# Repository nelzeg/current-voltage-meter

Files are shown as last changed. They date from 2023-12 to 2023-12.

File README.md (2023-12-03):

# Current and Voltage Meter

Battery-powered electronic circuit that wirelessly measures and transmits the voltages and currents generated by two solar panels used to power an LED-illuminated plant growth system.

> Download the full [report](./Current_Voltage_Meter_Spanish.pdf)

## Content
- [Operation Mode](README.md#operation-mode)
- [Schematic](README.md#schematic)
- [PCB](README.md#pcb)

### Operation Mode
- Detection system that can measure voltages up to 25 [V] and currents up to 5 [A].
- Operating time range 9:00 AM - 4:00 PM.
- The system senses current 3 times during the first 15 minutes of each hour, the remaining 45 minutes it enters deep sleep mode..

### Schematic
Main components:
- **`INA219AIDR` current sensor** from *Texas Instruments*
- **`ESP32-WROOM-32E` microcontroller** from *Expressif*
- **`TPS62840` DC-DC converter** from *Texas Instruments*

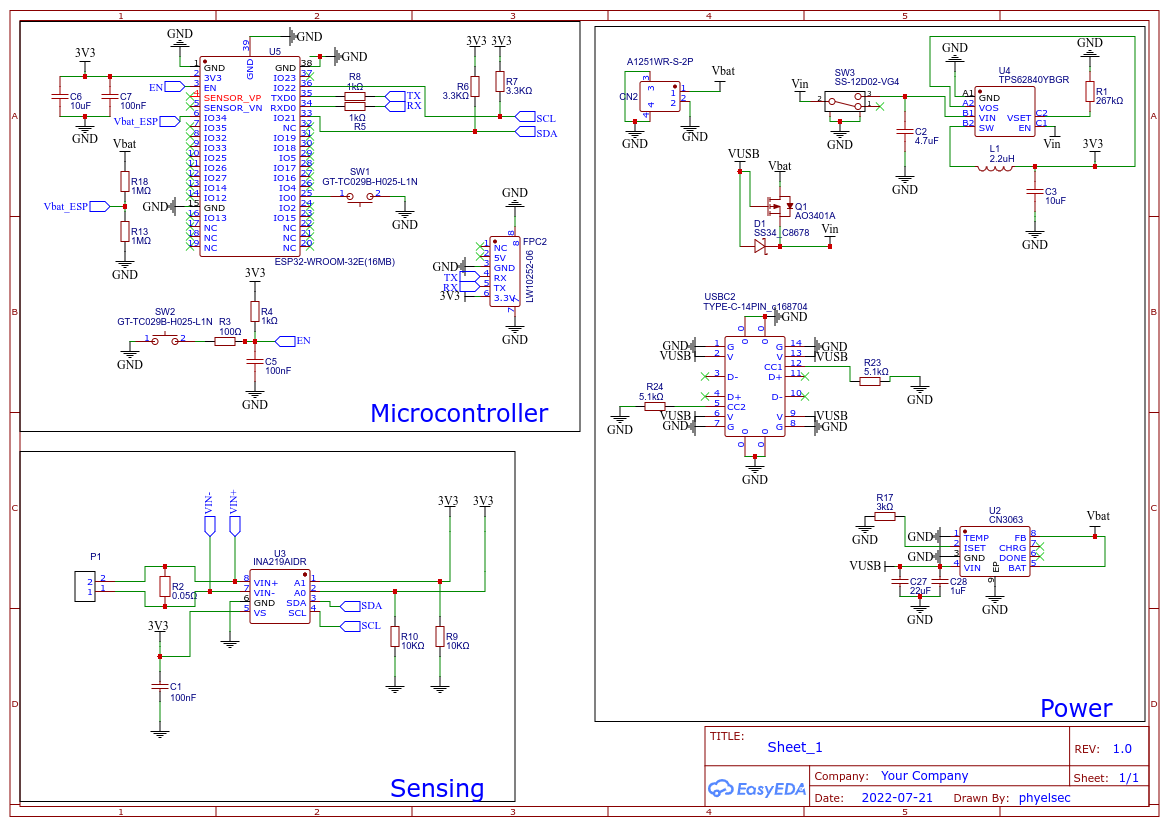
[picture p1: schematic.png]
Schematic


### PCB
- **EDA Tool**: EasyEDA
- **Board Dimensions** : `36.40mm x 44.95mm`
- **Power Tracks `Vin, 3.3V, Vbat, Vin+, Vin-` widths** : min `0.3mm`, max `0.5mm`
- **Signal Processing Tracks Widths** : min `0.254mm`
- **Track Spacing** : `0.4mm`
- **Top View** : Power and processing blocks.
- **Bottom View** : Sensing blocks.

> Download the [gerber files](./Gerber/)

#### Top View
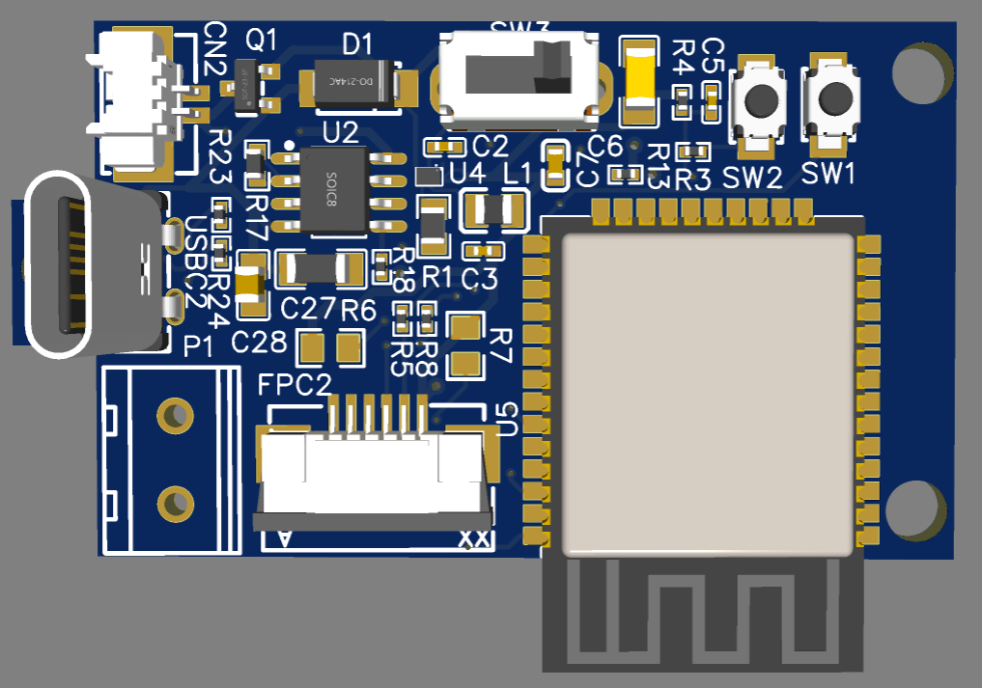
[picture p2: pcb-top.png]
PCB top view


#### Bottom View
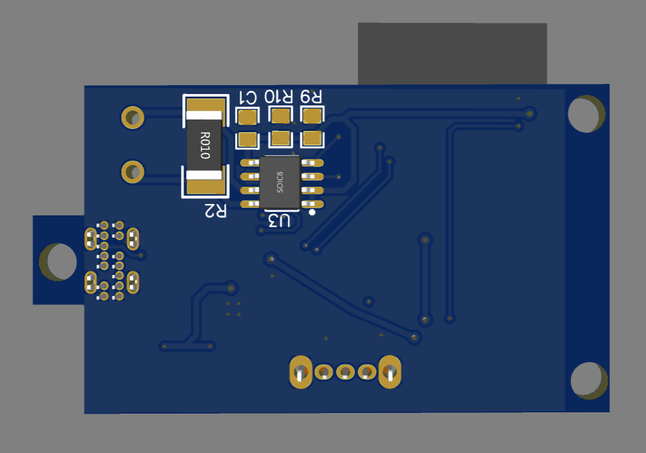
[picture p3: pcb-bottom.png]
PCB bottom view


#### Casing
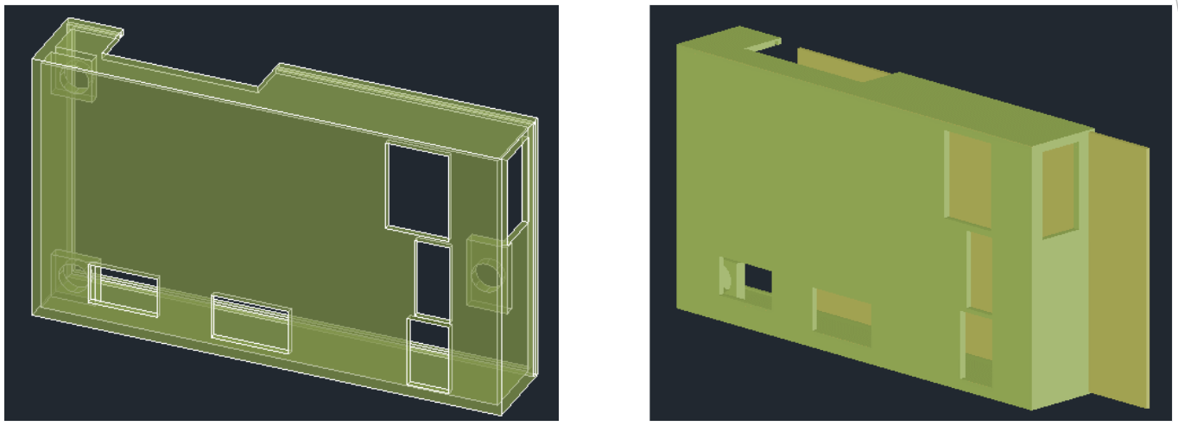
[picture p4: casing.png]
Casing


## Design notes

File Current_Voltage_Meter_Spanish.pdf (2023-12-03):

Trabajo Final Diseno de Sistemas Electr ˜ | onicos ´

# Medidor de Corriente y Voltaje

Bryan Jesus L ´ | opez Gonz ´ | alez - 2180407 | Angel Mauricio Ardila Barba - 2180394 ´
Erika Yesenia Suarez Bonilla - 2180376 | Nelson Jos ´ | e Rodr ´ | íguez Sierra - 2132410
Escuela de Ingenierías Electrica, Electr ´ | onica y Telecomunicaciones ´
Universidad Industrial de Santander Bucaramanga, Colombia
2022
I. OBJETIVOS
A. GENERAL
Disenar un circuito electr ˜ | onico alimentado con bater ´ | ía que
mida y transmita inalambricamente tensiones y corrientes ´ generadas por dos paneles solares utilizados para la alimentacion de un sistema de crecimiento de plantas iluminado ´ con diodos LEDs.
B. ESPECÍFICOS
- Disenar la PCB del circuito electr ˜ | onico. ´
- Seleccionar un modulo o un microcontrolador que per- ´
mita transmitir inalambricamente los datos de la tensi ´ | | on, ´
corriente y potencia electrica medidos a un celular. ´
- Proponer un sistema de sensado que permita medir tensiones de hasta 25 V y corrientes de hasta 5 A.
- Seleccionar los dispositivos electronicos a usar en el ´ circuito de la mejor manera posible, en donde se tenga en cuenta el tamano, consumo y precio. ˜

II. INVESTIGACIONES PREVIAS
A. Celdas Fotovoltaicas:
Los paneles solares son dispositivos compuestos por diferentes elementos, pero el principal de estos son las
celdas o celulas fotovoltaicas. Las celdas fotovoltaicas est ´ | | an´
basadas en el principio del efecto fotovoltaico, es decir, en la
conversion de luz solar a energ ´ | ía electrica [ ´ | Ein67]. Cada celda
esta fabricada a partir de silicio dopado. Este dopaje, necesario para crear inestabilidad electrica, es el que permite que se ´ generen pares electron-hueco cuando inciden fotones sobre ´ el material. Para su uso practico, las celdas son conectadas a un circuito externo, permitiendo la circulacion de un flujo ´
neto de cargas o corriente electrica en todo el sistema. [ ´ | Ate19]

Aunque en la actualidad existen muchos tipos de celdas
fotovoltaicas segun su material de fabricaci ´ | | on, tales como de ´
película fina, perovskita y celdas organicas, existen dos tipos ´ principales que son usados ampliamente en instalaciones residenciales y comerciales: las celulas monocristalinas y ´ policristalinas de silicio. [Ene20]
B. Sensor de Corriente:
Uno de los componentes fundamentales del proyecto es el sensor de corriente. A partir del hecho de que cuando fluye una corriente se produce una caída de tension y se genera ´
un campo magnetico, las formas de medici ´ | on de corriente se ´
clasifican como directa o indirecta.

La forma directa se basa en la ley de Ohm, esto es, midiendo la caída de voltaje en el elemento por el cual fluye la corriente. Por otro lado, la forma indirecta consiste en la
medicion del campo magn ´ | etico generado por la corriente que ´
fluye a traves de ´ | el. [ ´ | Pre18]
C. Tecnologías de Comunicacion: ´
Existen diversas tecnologías de comunicacion inal ´ | ambrica ´
que posibilitan el envio y recepcion de informaci ´ | on entre ´
diversos dispositivos. Algunas de estas son Wifi, Bluetooth, Zigbee y Z-wave [zon21]. Basados en el alcance del proyecto, la tecnología seleccionada fue la Bluetooth en su version´
4.2 que esta implementada en el ´ | ESP32S (microcontrolador
usado en el proyecto). Esta a su vez se divide en Bluetooth Classic y Bluetooth Low Energy [Tut19].

La diferencia entre estas dos, es que la Bluetooth Classic
es ideal para conectar telefonos m ´ | oviles a los aud ´ | ífonos
inalambricos, mientras que la Bluetooth Low Energy es una ´ version de ultra baja potencia enfocada para sensores de baja ´ potencia, esto es, para aplicaciones que no requieran conexion´
permanente y que estan alimentadas por bater ´ | ía. [Uni19]
D. Crecimiento de Plantas:
Para el proceso de fotosíntesis, las plantas utilizan solo ´ un rango del espectro de luz solar que reciben (luz roja y azul), convirtiendo en calor el rango restante, dificultando su crecimiento y floracion. ´
Por esta razon, desde hace algunos a ´ | nos, se ha buscado ˜
optimizar la produccion de flores (orqu ´ | ídeas, rosas,
crisantemos) o cultivos de diverso tipo (tomate, pimienta, albahaca, lechuga) en invernaderos o cultivos hidroponicos ´

[Wik22] haciendo una transicion de iluminaci ´ | on solar por ´
una artificial.

De entre las diversas alternativas artificiales disponibles, la mas atractiva en la actualidad es el cultivo interior con diodos ´ emisores de luz (LED).

Esta tecnología brinda muchas ventajas, ademas del ahorro ´
energetico, entre ellas est ´ | a el control del espectro de luz ´
que reciben las plantas, aumentando exponencialmente la produccion de dichos cultivos, sin afectar la calidad de estos ´ respecto a otras formas de iluminacion tradicional, como el ´ uso de lamparas incandescentes.

Entre los tantos beneficios que brinda esta tecnología es que puede ser hasta 5 veces mas eficiente en el consumo ´ de energía, no genera exceso de calor danino a las plantas, ˜ estas pueden absorber cerca del 90% de la luz emitida por las lamparas, las que a su vez presentan una mayor vida util ´ respecto a otras alternativas. [Hoy]

El hecho de que el sistema de iluminacion sea mucho mas ´ eficiente en su consumo de potencia, implica que una mayor parte de la energía proveniente del sistema fotovoltaico puede ser utilizada en otras partes del proceso de produccion. ´

E. Mapas solares:
Teniendo en cuenta que este un sistema que sensa corriente y voltaje provenientes de generacion fotovoltaica se hizo una ´
investigacion para determinar por cuanto tiempo tendr ´ | ía que
funcionar este sistema.

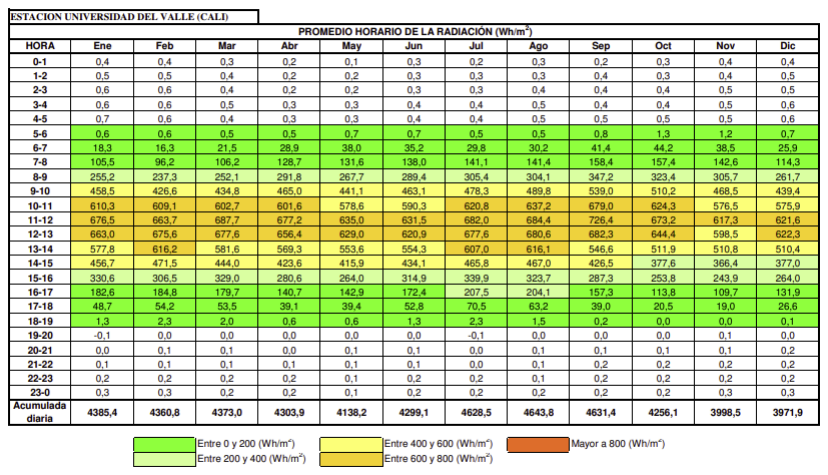
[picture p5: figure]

Fig. 1. Horarios y radiacion solar en Cali, Colombia. Obtenido de: [ ´ | Atl]

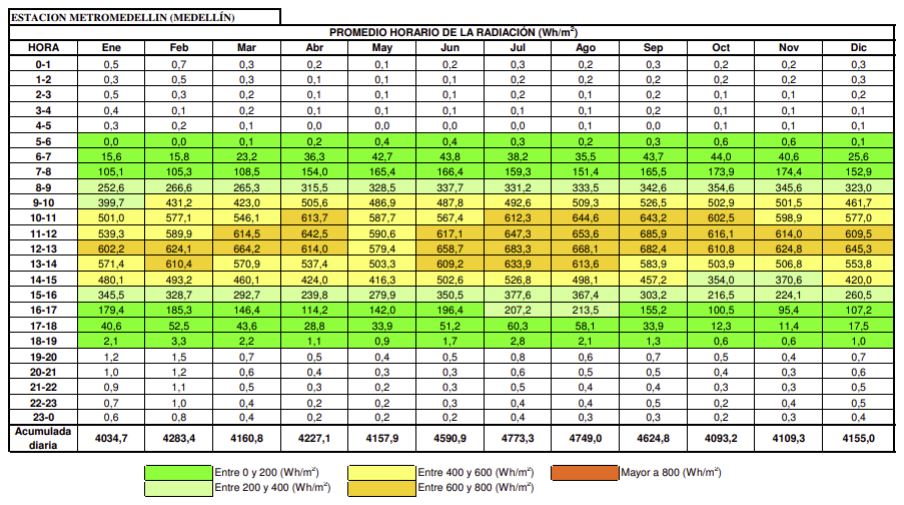
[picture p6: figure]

Fig. 2. Horarios y radiacion solar en Medell ´ | ín, Colombia. Obtenido de: [Atl]

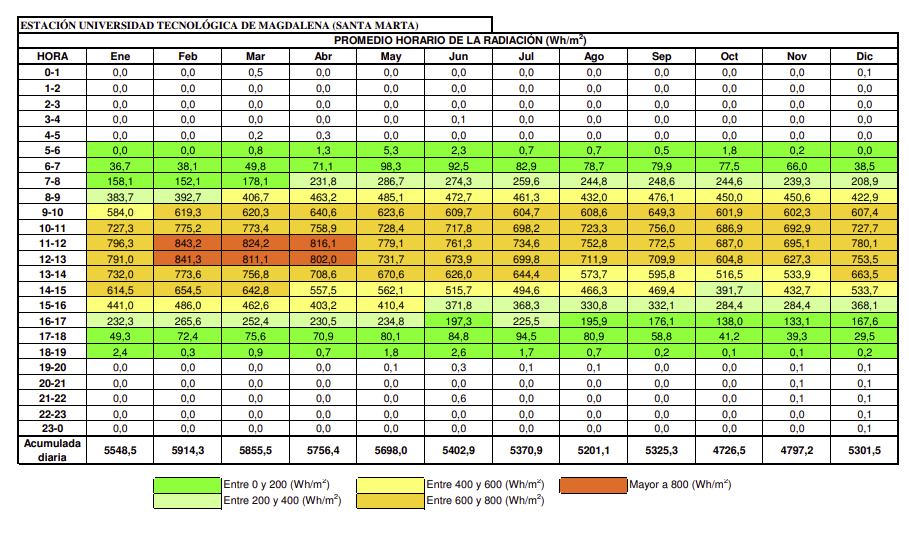
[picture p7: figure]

Fig. 3. Horarios y radiacion solar en Santa Marta, Colombia. Obtenido de: ´ [Atl]

En las figuras 1, 2 y 3 se pueden apreciar unas tablas en las que se presenta la cantidad de radiacion presente en una hora ´ determinada del día y a lo largo de los meses del ano. Como ˜ parte del ejercicio se estudiaron tres ciudades: Medellín, Cali y Santa Marta, en todos los casos se hace evidente que entre 8 y 9 de la manana empieza a ser significativa y esto hasta las 3 ˜ pm. Esto fue un estudio que sirvio para seleccionar el criterio ´ de funcionamiento del sistema que se explica mas adelante. ´

III. DISENÕ PROPUESTO
A. Arquitectura propuesta
En la figura 4 se muestra un diagrama de como se concibió inicialmente el diseno de este sistema, previa a la etapa de ˜ seleccion de componentes. ´

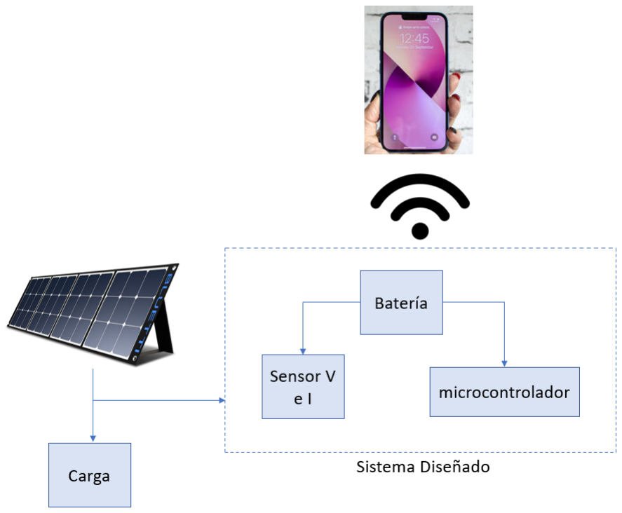
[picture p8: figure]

Fig. 4. Arquitectura propuesta para el sistema

B. Seleccion de componentes ´
El sensor de corriente usado en este proyecto, fue el integrado INA219 desarrollado por Texas Instruments, El cual permite medir voltajes de hasta 26 volts y dependiendo del valor de resistencia de shunt que se escoja se define la corriente maxima. ´

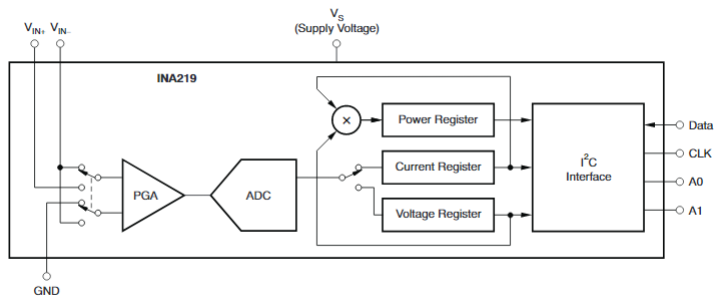
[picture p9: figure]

Fig. 5. esquematico del INA219 ´

Si embargo los valores de tension y corriente para los ´ que viene configurado el sensor INA 219 no cumplen con el requerimiento de esta aplicacion; es por ello que se debe ´ recurrir a modificar los parametros internos del mismo, como ´ se muestra en la figura 5, el INA219 contiene internamente un PGA (Programmable Gain Amplifier) que al configurarse
para la resolucion m ´ | axima de la medici ´ | on (PGA = 8) tiene ´
un voltaje maximo de shunt de 320 mV, escogiendo una ´ resistencia de valor 50 miliohms permite una corriente maxima ´ de 6.4 [A], valor de corriente que excede satisfactoriamente los requerimientos para este proyecto.

Adicionalmente, por su versatilidad, funcionalidades ade-cuadas para este tipo de aplicaciones y documentacion´ disponible, se escogio como microcontrolador un ESP32- ´ WROOM-32E (figura 6) el cual cuenta con una antena de 2.4 GHz que permite operar en los protocolos Bluetooth (4.2 en el caso de esta ESP32) y WiFi.

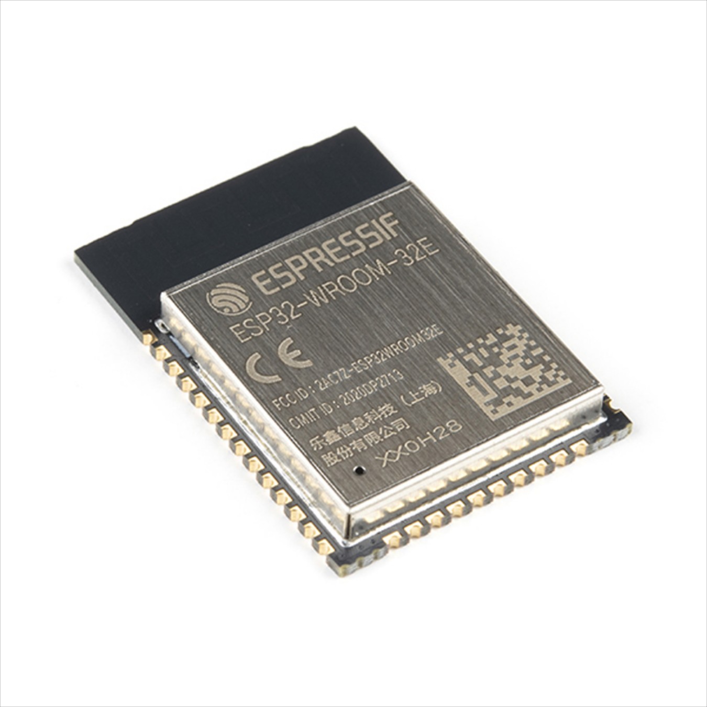
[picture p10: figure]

Fig. 6. ESP-WROOM-32E

Considerando que se busca proponer un diseno que est ˜ | é
asociado a baterías recargables y no requiera cambiar las baterías en un tiempo de por lo menos una semana laboral, es decir 5 días calendario en funcionamiento. Es necesario primero definir el funcionamiento que va a tener el sistema para así poder estimar el consumo del mismo y con ello las características necesarias para lograr los requerimientos respecto a las baterías.
Tomando | en | consideracion | el | consumo | energ ´ | etico ´
del sistema presentado posteriormente en la seccion´ Funcionamiento del sistema y con una estimacion del ´ consumo de potencia de los otros elementos del sistema se tiene un consumo de corriente general estimado de 500[mA] por 2 horas al día en el peor de los casos.

Para que el sistema pueda funcionar durante 5 días seguidos bajo ese consumo hipotetico se debe asegurar un arreglo de ´ baterías de por lo menos 5000[mAh], en este caso se escogió un par de baterías recargables de ion de litio 18650 de 4.2 V y 6800[mAh]

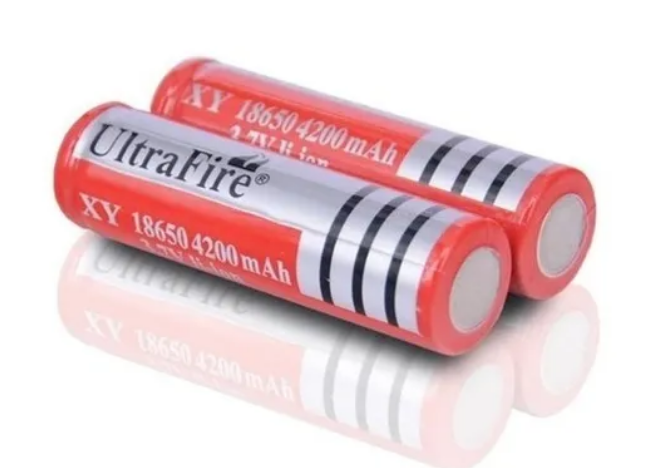
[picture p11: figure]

Fig. 7. Baterías escogidas para alimentar el sistema

Con las que el sistema puede durar mas de 6 d ´ | ías trabajando
con el modo de funcionamiento planteado bajo la misma carga de baterías.
C. Esquematico ´
En la siguiente figura se puede observar el esquematico ´ del circuito, construido en EasyEDA con los elementos seleccionados y anteriormente descritos. En este se muestran las conexiones entre los elementos que permiten el funcionamiento del sistema.

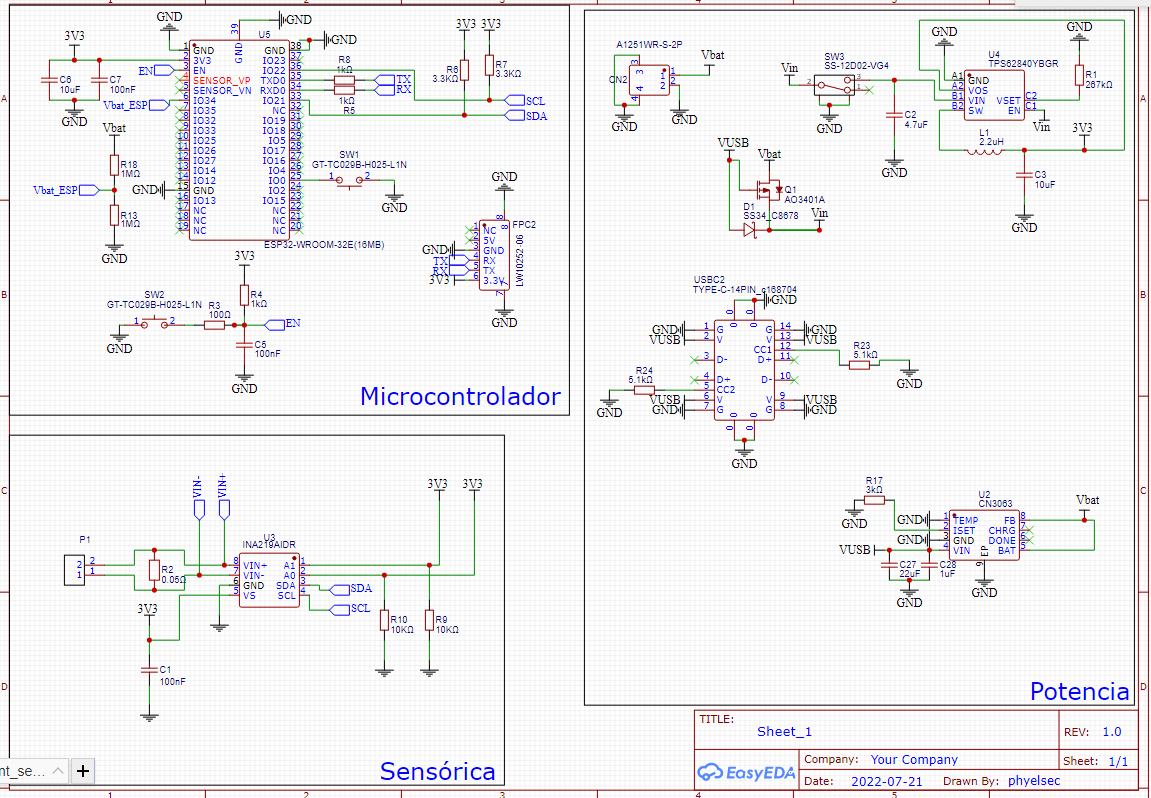
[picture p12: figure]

Fig. 8. Esquematico ´

Como se puede observar en la figura 7 el esquematico est ´ | á
compuesto principalmente por tres partes:
- Microcontrolador:
Esta parte contiene los elementos y conexiones necesarias para que el microcontrolador funcione: Tiene las resistencias de pull up de SDA y SCL, contiene capacitores en la alimentacion de 3.3 V, adicionalmente cuenta con un ´ conector cuyas conexiones son RX y TX, de esta manera se puede programar el microcontrolador a traves de la ´ conexion externa de un convertidor USB a TTL. En la ´ parte inferior se muestra el circuito que permite resetear el microcontrolador a traves de un switch. Finalmente, en ´ la parte izquierda se cuenta con un divisor resistivo que
permite medir la tension de la bater ´ | ía.

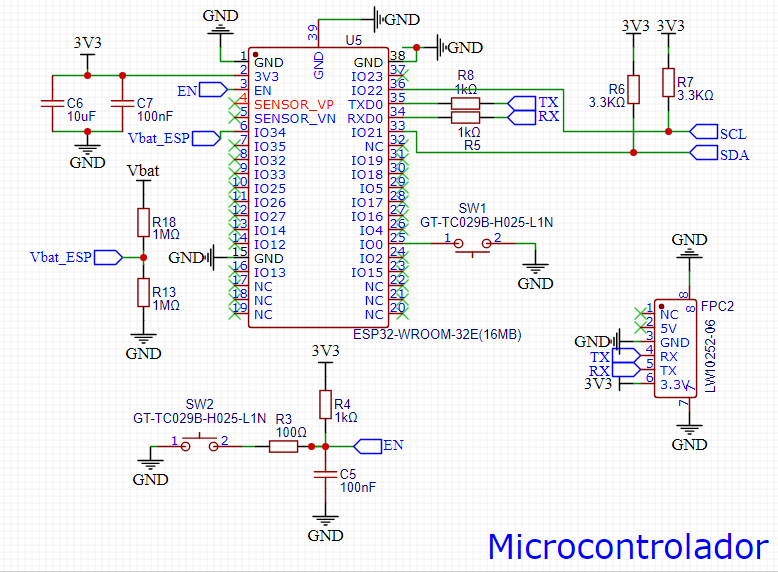
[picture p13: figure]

Fig. 9. Esquematico Microcontrolador ´

- Sensorica ´ :
En esta parte el elemento central es el ina219 con las respectivas conexiones recomendadas por el datasheet para que funcione adecuadamente en este contexto, en este apartado uno de los detalles mas importantes es ´ la resistencia de shunt de 50 miliohms, la cual fue seleccionada de 2 W (teniendo en cuenta que la corriente
maxima a soportar en esta aplicaci ´ | on es de 5 [A]). ´
Adicionalmente, el INA219 permite programar, a traves´ de las conexiones de resistencias en los pines A0 y A1, la direccion de esclavo en el protocolo I2C, en este caso ´
se dejo una direcci ´ | on fija correspondiente a tener las dos ´
direcciones conectadas a alimentacion positiva, ya que ´ este es el unico sensor en el circuito y no se requiere de ´ cambiar esta direccion frecuentemente. ´

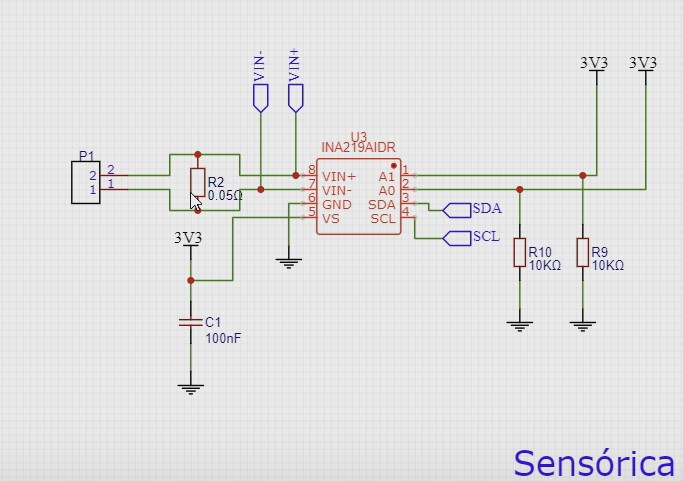
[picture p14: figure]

Fig. 10. Esquematico Sens ´ | orica ´

En la figura 10 aparte de las conexiones típicas se observa el enlace de los pines SCL (System Clock) y SDA (System Data) entre la ESP-32S y el INA260, siendo SCL la línea de pulsos de reloj para sincronizar el sistema y SDA la línea para la transferencia de datos.

- Potencia:
Esta seccion contiene todos los elementos que permiten ´
que el sistema se energice, ya sea a traves de bater ´ | ías o
por un conector USB-C para cargar el circuito.
Se escogio un conversor DC - DC TPS62840 el cual ´ funciona como reductor de tensiones de hasta 6.5 V. Este circuito permite obtener una tension de salida de ´ 3.3 V para alimentar el microcontrolador y el sensor, fue
seleccionado porque, ademas ofrecer la tensi ´ | on de salida ´
requerida, tiene una corriente de reposo de 60 [nA] lo cual es ventajoso para esta aplicacion que funciona con ´ batería.

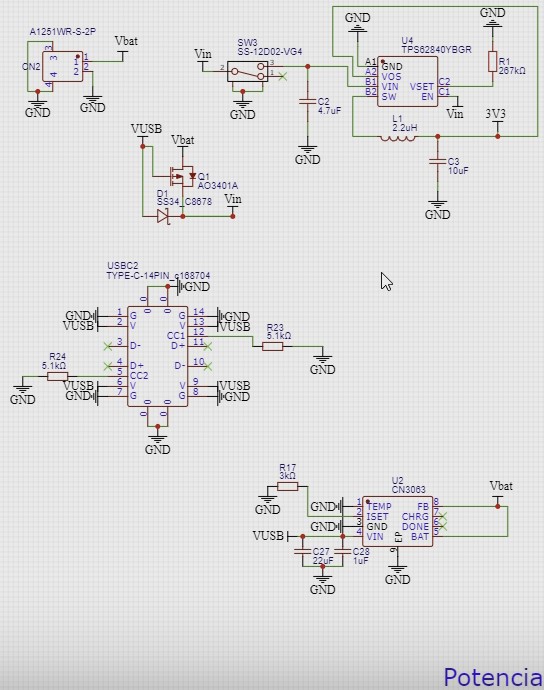
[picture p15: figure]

Fig. 11. Esquematico Potencia ´

El sistema de potencia tambien contiene el integrado CN3063 ´ que funciona bien con este tipo de baterías como la escogida, pues este permite cargar la batería a 4.2 V. Estando conectado como se presenta en el esquematico, tiene una corriente ´ maxima de carga de 600 [mA]. ´
El arreglo en la parte superior compuesto del MOSFET canal P con diodo Schottcky permite que el circuito se alimente con la batería y en caso de que esta este cargandose, ´ el sistema sera alimentado por la corriente proveniente de del ´ cargador, el cual se conecta al sistema a traves de un conector ´ USB tipo C.
D. Funcionamiento del sistema
El planteamiento que se le dio al funcionamiento del sistema esta enfocado a ser aplicable en el contexto para el ´ cual se plantea. Se opto por un funcionamiento general del ´ sistema tipo rutina; rutina la cual esta dividida en dos tipos ´ de funcionamiento:
1) Rutina de lectura de datos: Aquí el sistema va a
entrar en un bucle por el n ´ | umero de horas donde interese ´
monitorear el rendimiento del arreglo de paneles. En el caso ´ de Medellín se determino previamente que el momento donde ´ la radiacion solar se empieza a considerar relevante es a las 9 ´ AM hora local, y este intervalo termina a las 4PM. Tomando en consideracion que el sistema ha de funcionar operado ´ por baterias y que el sistema no amerita por su naturaleza un monitoreo constante durante este intervalo de tiempo
esa opcion no es lo m ´ | as eficiente, por lo que se plante ´ | o un ´
funcionamiento por intervalos.

Modo intemitente:
El muestreo de datos se va a realizar 3 veces en un lapso de 15 minutos, despues de leer los datos 3 veces durante ´ esos 15 minutos el microcontrolador entra en estado de modo
sueno profundo donde apaga casi todos sus perif ˜ | ericos a ´
excepcion de RTC y del ULP Processor, su consumo de ´ corriente en este modo se reduce al maximo permitido de ´ 10[uA], el microcontrolador va a estar en modo ahorro de energía durante los siguientes 45 minutos hasta el siguiente comienzo de hora donde todo esto se repetira cada hora ´
dentro del intervalo de radicion solar de inter ´ | es. ´

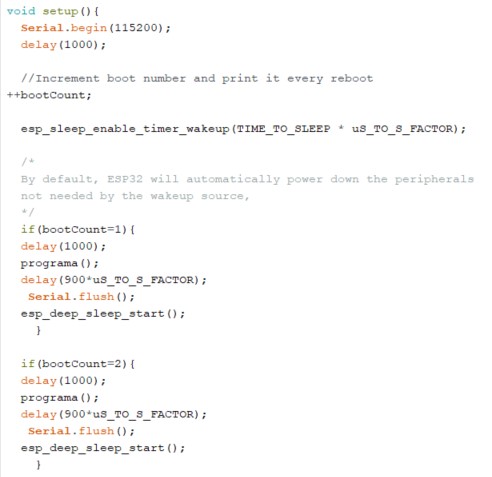
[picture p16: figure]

Fig. 12. Codigo que permite el funcionamiento del modo intermitente ´

Cada vez que el el micro-controlador regresa del modo de sueno profundo aumenta un contador interno por lo que ˜ se logro que funcionara respecto a esta variable, el contador ´ empieza en 1 por defecto por lo que entra al primer if, ejecuta el programa de lectura y recepcion de datos y luego ´ de 900 segundos que representan los 15 minutos planeados el sistema entra en modo sueno profundo por 45 minutos y ˜ vuelve a funcionar normal pero esta vez con el contador en 2 por lo que entraría al segundo if repitiendo el mismo proceso

por las veces necesarias.

Para tener acceso al codigo de la ESP32 con esta y sus ´ futuras versiones se puede acceder al siguiente link del repositorio de GitHub:
Enlace al Repositorio (https://github.com/AngelMau05/Proyecto_Diseno)
2) Rutina de envío y recepcion de datos ´ | : El envío de
datos esta estrechamente enlazado con la lectura de los ´ mismos, cada 5 minutos el micro-controlador ESP32 va a realizar la lectura de datos, luego de realizar esta lectura los datos son enviados vía Bluetooth, este proceso se repite 3 veces en los mismos primeros 15 minutos de cada hora. Representando un consumo de corriente de 130 [mA] cuando transmite y de 100[mA] cuando recibe.

Modo de Sueno Profundo constante: ˜
A las 4PM en el caso de Medellín o a la hora en la que deje de ser relevante el rendimiento del arreglo de paneles la ´ ESP entra en modo de sueno profundo otra vez, pero esta ˜ vez lo hace hasta la hora en la que la radiacion empieza a ser ´ relevante otra vez al siguiente día.

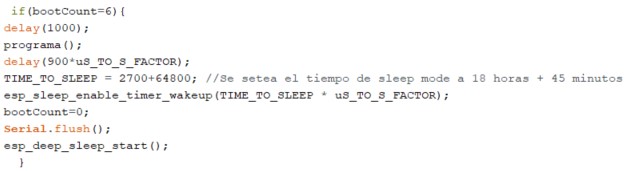
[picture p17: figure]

Fig. 13. Codigo que permite entrar al Sleep mode por varias horas ´

E. Sistema de comunicaciones
El envío de los datos se realiza por medio de un el enlace entre el micro-controlador y un dispositivo movil ´ usando el protocolo Bluetooth, actualmente esta enfocado ´ a dispositivos Android que cuenten con Bluetooth 2.0 o superior debido a que la App fue disenada teniendo en cuenta ˜ esas consideraciones.

Micro-Controlador:

El micro-controlador toma los datos de variables del sensor
INA260 despues de incluir la respectiva librer ´ | ía por medio
de: #include <Adafruit INA260.h> con unas simples líneas de codigo: ´

Fig. 14. Adquisicion de datos del INA260 ´

Los datos son leídos por el micro-controlador haciendo uso del protocolo estandar I2C.Una vez leidos los datos son ´ guardados como componetentes de un vector de 3 elementos tipo string separados por coma, esto ultimo es relevante pues ´ en la apliacion m ´ ovil se va a recibir el string completo y para ´ separar cada variable se va a tomar el caracter de la coma ´ como separador.

La librería Bluetooth estandar ”BluetoothSerial.h” es aque- ´ lla que permite establecer esa comunicacion Bluetooth con la ´ ESP32. Cada 5 minutos dentro del intervalo activo de modo ´ intermitente se cumple el periodo pogramado por lo que cada vez que se cumpla ese tiempo se van a actualizar los valores recibidos por el INA260 y se van a trasmitir por medio de Bluetooth.

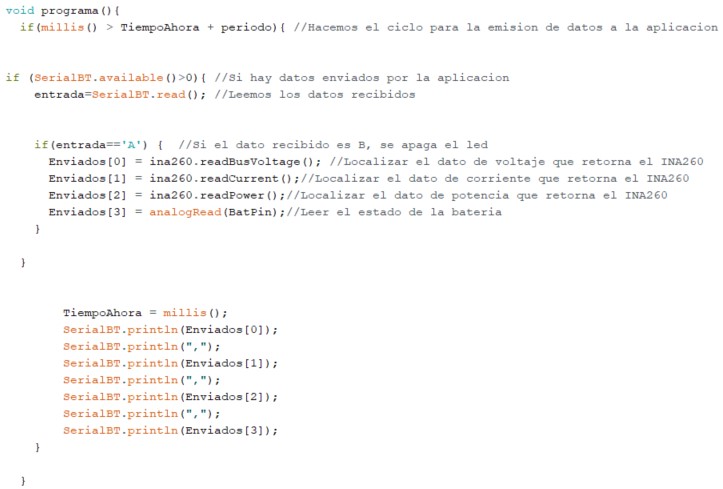
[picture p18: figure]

| Fig. 15. Actualizacion y env ´ | ío de los datos
Aplicacion M ´ | ovil: ´

Como ya se ha venido mencionando la otra parte fundamental de este sistema de comunicaciones es el sistema
de recepcion de datos. Este sistema est ´ | a enfocado a una ´
aplicacion m ´ | ovil que se describe a continuaci ´ | on. ´

La aplicacion fue realizada completamente en el ambiente ´ de AppInventor, esta cuenta con la siguiente interfaz:

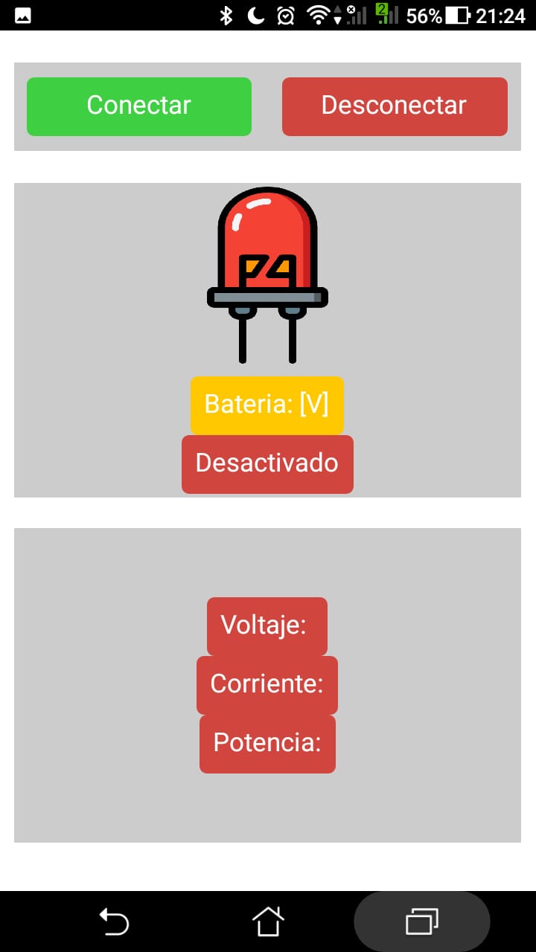
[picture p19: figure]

Fig. 16. Interfaz aplicacion m ´ ovil ´

El panel superior es aquel que me permite conectar o desconectar el enlace Bluetooth con el micro-controlador.

La imagen del LED es un boton que me permite ´ realizar una nueva lectura de los datos que me retorna el micro-controlador. Cada vez que este se activa manda un request al micro-controlador para buscar y leer los nuevos datos en el caso que se haya cumplido el periodo de 5 minutos.

Debajo del LED se ecuentra el espacio donde se va a reflejar el estado de la batería cuando se actualice la informacion. ´ En la mitad inferior se encuentran los tres espacios donde
seran visualizadas las tres variables de inter ´ | es en este caso. ´

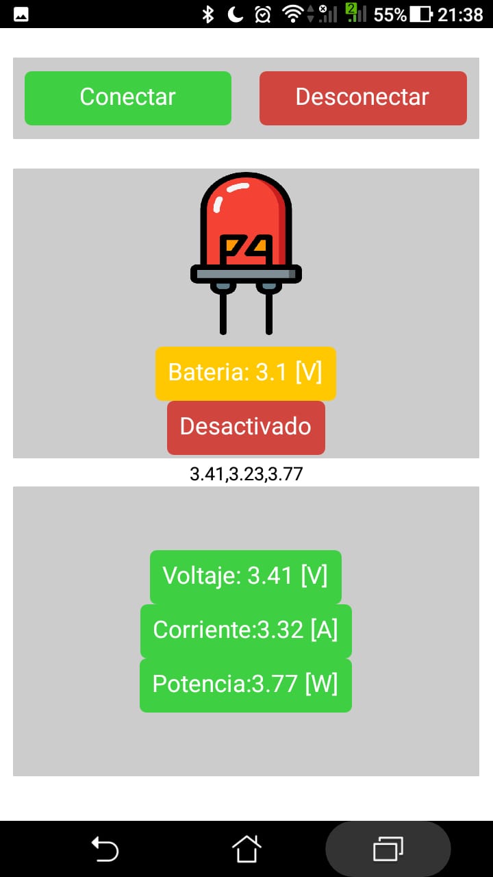
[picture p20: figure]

Fig. 17. Apliacion mostrando los datos recibidos ´

Un analisis m ´ | as a detalle del funcionamiento m ´ | as a detalle ´
de este sistema con unos ejemplos se presenta en la siguiente sub-seccion: ´
F. Prueba de Funcionamiento:
Debido a que la compra de componentes no se ha realizado en este punto del proyecto, la prueba de funcionamiento está enfocada a simulaciones, la idea era para realizar una prueba donde no solo se realice un enlace Bluetooth sino que la
programacion de todo el funcionamiento sea lo m ´ | | as parecida ´
posible a la que se va a implementar en el controlador; es por ello que se realizo la prueba en Proteus. ´

Este software permite ingresar codigo al micro-controlador, ´ y realizar un enlace Bluetooth haciendo uso del Bluetooth de la computadora como si fuese el asociado al micro-controlador.

Aquí hay que hacer unas aclaraciones y es que en este software no se cuenta con un modulo de ESP32 funcional, por ´ lo que no se puede hacer la simulacion exacta, sin embargo, ´ sí se cuenta con la opcion de realizar esto con un Arduino ´ que permite cargar el codigo funcional que no presenta casi ´
variaciones al codigo que se carga en la ESP32 y un m ´ | odulo ´
HC-05 para establecer el enlace Bluetooth requerido.
Se realizaron unas pruebas basicas de comunicaci ´ | on con ´
una aplicacion de celular confirmando que s ´ | í cumplía con el
comportamiento basico descrito, por lo que se entr ´ | o en el ´
proceso de montar el codigo planteado para la ESP32 en el ´
modulo de siulaci ´ | on de Arduino en Proteus ”Simulino”. ´

Aquí tambien es importante resaltar que no existe en ´ ninguna plataforma de la que se tenga conocimiento un
modulo que presente el funcionamiento del m ´ | odulo INA260, ´
sin embargo como ya se menciono antes el obtener los datos ´
de interes de este m ´ | odulo no es una tarea compleja por lo ´
que se puede dar por hecho que se cuenta con esas variables a la hora de simular y efectivamente eso se hizo, se trabajó con valores aleatorios dentro de un rango limitado para representar su funcionamiento.

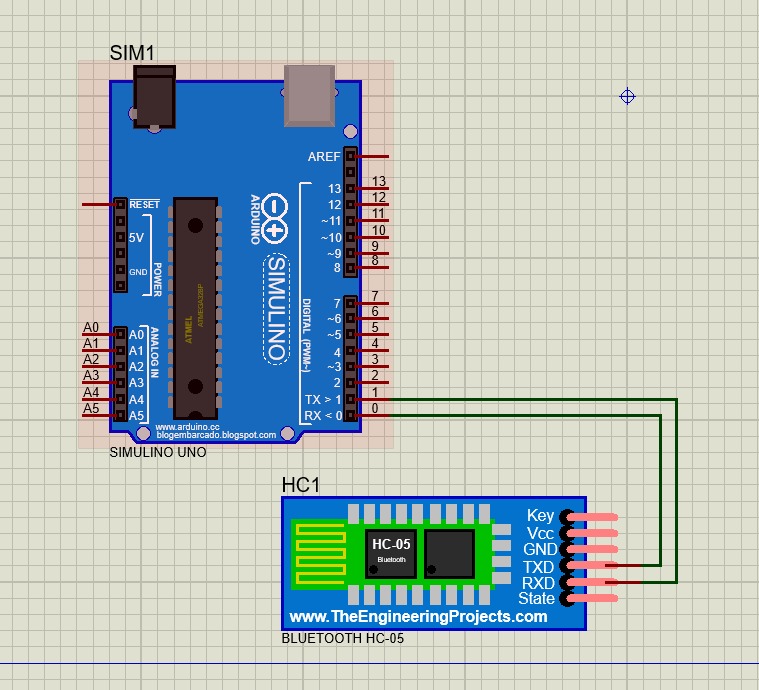
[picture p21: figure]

Fig. 18. Esquematico planteado para la simulaci ´ | on´
A continuacion se presenta el enlace a un v ´ | ídeo en YouTube
de 5 minutos realizado por uno de los integrantes de este
grupo donde se dan mas detalles y se ve con m ´ | as claridad ´
el funcionamiento en tiempo real de estas pruebas que se hicieron en las primeras versiones del proyecto para verificar los principios de funcionamiento de la comunicacion. ´
Video Simulacion con Explicaci ´ | on´ (https://youtu.be/s59fojakUEA)
G. Diseno de PCB ˜
El diseno de la PCB se hizo en el software ˜ | EasyEDA
[Eas] debido a las ventajas que este ofrece, pues se ajustan y permiten el cumplimiento de los requerimientos de este trabajo:
- No requiere instalacion, est ´ a basado en la nube. ´
- Permite el diseno de PCB desde el navegador. ˜
- Es un software gratuito.
- Tiene una amplia biblioteca de componentes electronicos. ´

- Permite importar disenos de otros softwares como Al- ˜ tium, Eagle y KiCad.
- Permite el trabajo colaborativo en línea.
- Dispone de visualizacion 3D. ´
Para el diseno se tuvo en consideraci ˜ | on que los ´
componentes de los bloques funcionales (sensorica, potencia, ´ procesamiento) estuvieran juntos, esto con el fin de facilitar tareas de troubleshooting o deteccion de fallas en caso de ´ presentarse, de modo que en la capa superior fueron ubicados los bloques de potencia y procesamiento [Fig. 19] y en la
capa inferior el de sensorica [Fig. ´ | 20].

Las pistas de Vin, 3.3V, Vbat, Vin+ y Vin- se disenaron ˜ con un ancho de mínimo 0.3mm y maximo 0.5mm dado que ´ eras las que conducían una mayor intensidad de corriente. Las demas pistas que configuraban los circuitos integrados y ´ que formaban el bus I2C tenían un ancho mínimo de 0.254mm.

En base a la literatura sobre integridad de senal en circuitos ˜ impresos, durante el diseno se procuro no dividir demasiado ˜ el plano tierra y evitar pistas largas en paralelo para evitar la aparicion de ruido por acoplamiento. ´

Tambien se dise ´ | no en base a otras recomendaciones tales ˜
como:
- La mínima separacion entre pistas recomendada es de 0.4 ´ milímetros.
- El tamano exterior de los PADS debe ser como m ˜ | ínimo,
dos veces el tamano de la pista que lo conecte. ˜
- Hacer las pistas de alimentacion m ´ as gruesas debido a ´ que a traves de estas circula una mayor corriente. ´
- Elegir los caminos mas cortos para el trazado de pistas.
- Uso de planos de tierra y potencia para la reduccion de ´ ruido.
El diseno terminado present ˜ | o unas dimensiones de 30.48mm ´
x 44.95mm omitiendo la antena del modulo. Tomando en ´ cuenta esta ultima las dimensiones fueron de 36.40mm x ´ 44.95mm.
El diseno final de la PCB puede apreciarse en los siguientes ˜ renders 3D:

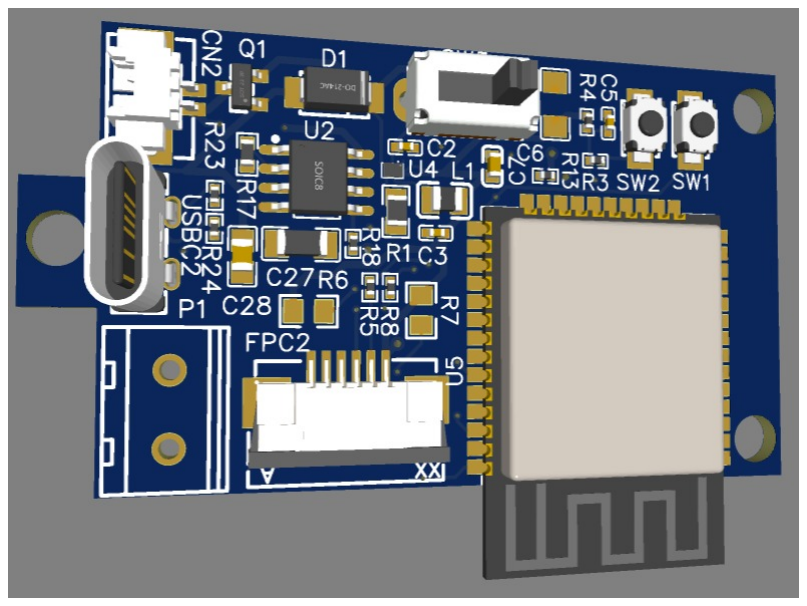
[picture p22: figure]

Fig. 19. Vista superior de la PCB

Fig. 20. Vista inferior de la PCB

IV. DISENO DE SOPORTE ˜

Con el fin de lograr un sistema compacto y robusto se
disena un soporte para la tarjeta dise ˜ | nada. ˜
En este diseno se tiene en cuenta las entradas, salidas y ˜ componentes que en algun momento pueden requerir contacto ´ con el exterior, tambien se hacen orificios para atornillar y ´ dejar la tarjeta fija en el soporte. Esto se puede observar en la figura 21.

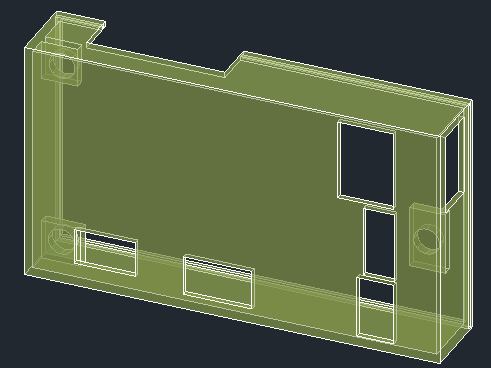
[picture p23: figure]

Fig. 21. Soporte

El soporte cuenta con una tapa deslizante que en caso de
requerir algun cambio puede ser retirada f ´ | acilmente. Esta se ´
puede observar en la figura 22.

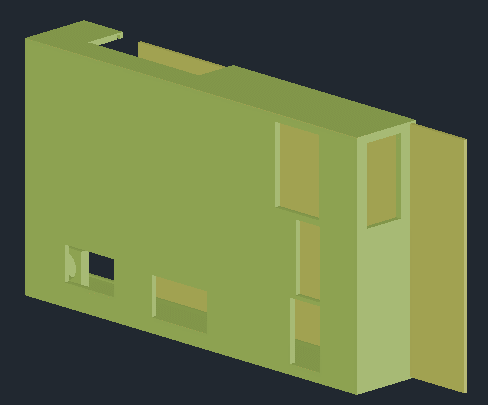
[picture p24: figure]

Fig. 22. Soporte

En la figura 23 se puede ver el resultado final del diseno, ˜ en el que se incluye el circuito disenado en un modelo 3D. ˜

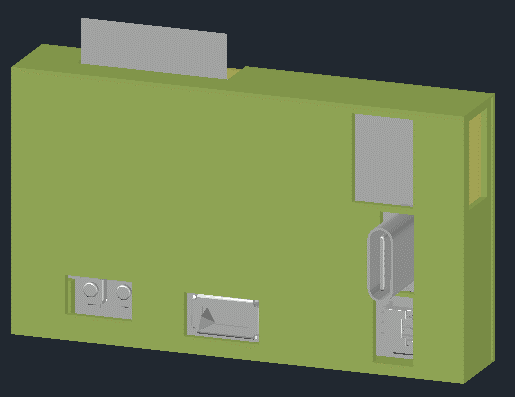
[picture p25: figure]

Fig. 23. Soporte

V. COSTOS
Easy EDA fue escogido no solamente por su funcionalidad (la cual es bastante buena), sino porque permite cotizar el costo de la PCB con los elementos selccionados a traves de ´ LCSC y mandar a la PCB directamente con JLCPCB.
- JLCPCB* - Empresa que fabrica PCB a precios muy bajos, con una alta calidad y en poco tiempo, mayores productores de PCB en china.

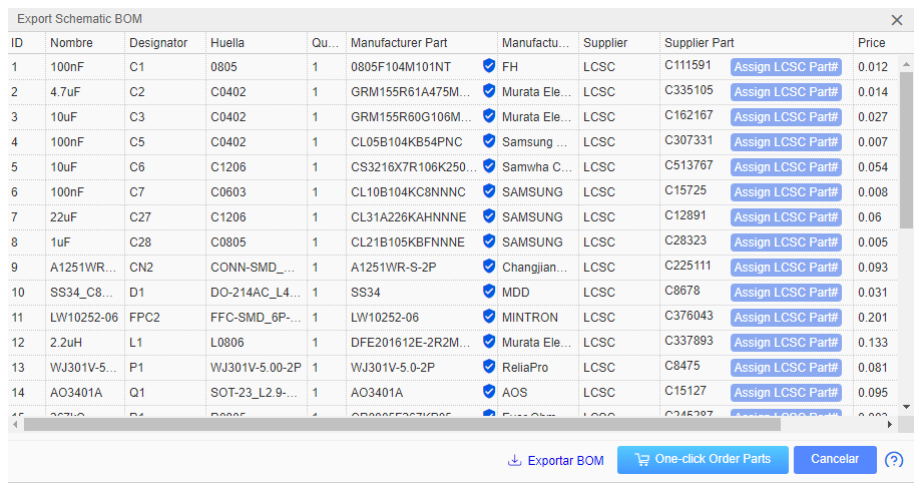
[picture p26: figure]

Fig. 24. Lista de materiales generada a partir del esquematico del circuito ´

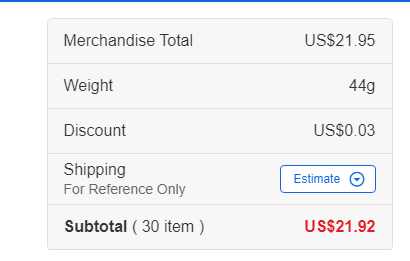
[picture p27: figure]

Fig. 25. Costo de los elementos seleccionados para el circuito

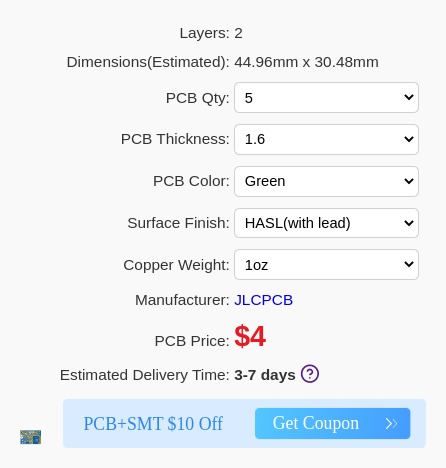
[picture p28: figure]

Fig. 26. Costo de la PCB

ITEM | Descripcion´ | Cant | Precio(COP)
Componentes | Todos los componentes generados en el esquematico ´ | | 98.300
Batería | Ultrafire 18650 Li-ion Recargable 6800mah 4.2v | 1 | 9.800
PCB | Costo impresion (JLCPCB)* ´ | 5 | 18.000
TOTAL | | | 126.100
TABLE I
MEDIDAS DE DESEMPENO GENERALES ˜

VI. OBSERVACIONES

- Una propuesta para futuros proyectos sería optimizar este diseno del sensor propuesto complementando la ˜
alimentacion de la bater ´ | | ía con un modulo pequeno de ˜
celdas solares y un regulador a fin de disenar un sistema ˜
autosuficiente en consumo energetico, similar a c ´ | omo se ´
alimentan hoy día algunos radios AM/FM que suelen usar los cultivadores en zonas alejadas de los pueblos.
- Las pruebas de funcionamiento simuladas a pesar de no contar con los elementos exactos con los que se plantea llevar a cabo el proyecto, cumplen con su objetivo, pues aquellos modulos alternativos tienen una forma de operar ´ muy similar o casi identica, dando confianza del proceso. ´
- El sistema propuesto cuenta con amplias opciones de mejora, ajustar los ciclos de funcionamiento de una forma mas amigable para el usuario como puede ser desde la ´
misma aplicacion m ´ | ovil, optimizar el c ´ | odigo del micro- ´
controlador para hacer mas efectivo el sistema o ampliar ´ su funcionamiento aumentando el numero de sensores ´ para poder medir variables en diferentes arreglos de paneles pues el protocolo I2C lo permite.
- Para la construccion de este tipo de proyectos, en ´ los cuales se requiere la impresion de un circuito, ´ la adquisicion de microcontroladores y otro tipo de ´
elementos electronicos, es m ´ | as rentable la compra ´
de estos por internet en el exterior debido a su mas´ bajo costo, sin embargo, se debe contar con el tiempo suficiente para recibir los elementos pedidos y hacer el montaje.

VII. CONCLUSIONES
- Basandose en componentes de bajo costo o de libre ´ acceso se puede llegar a dar solucion a una necesidad ´ muy clara en la industria de forma eficaz y confiable siempre que se realice el debido proceso de diseno de ˜ todo el sistema.
- Luego de un detallado estudio para la seleccion de los ´ componentes del proyecto, desarrollo de la comunicacion´
inalambrica y dem ´ | as aspectos que se tuvieron en cuenta, ´
se llego a un dise ´ | no que cumple con requerimientos ˜
planteados en los objetivos.

REFERENCES
[Ein67] Albert Einstein. The Old Quantum Theory. http : //users.physik.fu-berlin.de/∼kleinert/files/eins lq. pdf. (http://users.physik.fu-berlin.de/~kleinert/files/eins_lq.pdf) (Accessed on 08/02/2022). 1967.
[Pre18] | Sensores de Presion. ´ | Tipos de sensores de corriente.
https : / / www . sensoresdepresion . top / 2020 / 02 / tipos - de - sensores - de - corriente . html. (https://www.sensoresdepresion.top/2020/02/tipos-de-sensores-de-corriente.html) (Accessed on 08/03/2022). 2018.
[Ate19] | Atersa. Como funciona una c ´ | elula fotovoltaica ´ | .
https : / / atersa . shop / como - funciona - una - celula -fotovoltaica/. (https://atersa.shop/como-funciona-una-celula-fotovoltaica/) (Accessed on 08/02/2022). 2019. [Tut19] Random Nerd Tutorials. ESP32 Bluetooth Classic with Arduino IDE - Getting Started — Random Nerd Tutorials. https : / / randomnerdtutorials . com / esp32-bluetooth-classic-arduino-ide/. (https://randomnerdtutorials.com/esp32-bluetooth-classic-arduino-ide/) (Accessed on
| 08/03/2022). 2019.
[Uni19] | Unitron. WiFi, Bluetooth, Zigbee y Z-Wave: Qué
son, diferencias y usos. https : / / www . adslzone . net / reportajes / tecnologia / estandares - conexion -inalambrica/. (https://www.adslzone.net/reportajes/tecnologia/estandares-conexion-inalambrica/) (Accessed on 08/03/2022). 2019.
[Ene20] | Cambio Energetico. ´ | Todo lo que necesitas saber
| sobre celulas solares fotovoltaicas ´ | | . https://www.
cambioenergetico . com / blog / celulas - solares -fotovoltaicas/. (https://www.cambioenergetico.com/blog/celulas-solares-fotovoltaicas/) (Accessed on 08/02/2022). 2020.
[zon21] | AZ adsl zone. WiFi, Bluetooth, Zigbee y Z-Wave:
Que son, diferencias y usos ´ | . https://www.adslzone.
net / reportajes / tecnologia / estandares - conexion -inalambrica/. (https://www.adslzone.net/reportajes/tecnologia/estandares-conexion-inalambrica/) (Accessed on 08/03/2022). 2021. [Wik22] Wikipedia. Hidroponía - Wikipedia, la enciclopedia libre. https : / / ehttps : / / es . wikipedia . org / wiki / Hidroponia. (https://ehttps://es.wikipedia.org/wiki/Hidroponia) (Accessed on 08/03/2022). July 2022.
[Atl] | Atlas. Atlas Interactivo - Radiacion IDEAM ´ | . http:
/ / atlas . ideam . gov. co / visorAtlasRadiacion . html. (http://atlas.ideam.gov.co/visorAtlasRadiacion.html)
| (Accessed on 08/05/2022).
[Eas] | EasyEDA. EasyEDA – Simulador de circuitos y
| diseno de circuitos impresos online ˜ | | . https://easyeda.
com/. (https://easyeda.com/) (Accessed on 08/03/2022).
[Hoy] La Finca de Hoy. Iluminacion LED para e acelerar ´ el crecimiento de las plantas - YouTube. https : / / www. youtube . com / watch ? v = HejD21kbL2M. (https://www.youtube.com/watch?v=HejD21kbL2M)
| (Accessed on 08/03/2022).

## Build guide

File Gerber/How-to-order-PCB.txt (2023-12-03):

How to Order PCB

Please refer to:
https://docs.easyeda.com/en/PCB/Order-PCB
